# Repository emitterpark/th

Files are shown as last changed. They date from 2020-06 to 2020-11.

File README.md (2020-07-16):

**LoRaWAN Outdoor Temperature & Humidity Sensor**

**SENSOR**

**Temperature;**

Range -40 to +125 C

Resolution 0.01 C

Accuracy tolerance +-0.2 C

**Humidity;**

Range 0 to 100 %RH

Resolution 0.01 %RH

Accuracy tolerance +-2 %RH

High and Low Alarms with hysteresis

**RADIO**

LoRaWAN Class A

Licence Free ISM Bands (EU868, US915..), Default EU868, 8 Channel

Up to 100mW (20dbm) output power

High sensitivity -148dbm

3dbi External Antenna

Long Range, greater than 10km line of sight

**POWER**

3.6V 9000mah ER26500 C Size LiSClO2

15uA sleep current

Up to 5 years battery life depending on send interval

Low battery alarm

**CONFIGURATION**

Configuration via USB, Pc, Phone, Tablet

Send Interval, 5min to 24h

High and Low Alarm thresholds

Full LoRaWAN parameters access

Over The Air Activation (OTAA) with DevEUI, AppEUI, AppKEY

**PHYSICAL**

Outdoor IP65 waterproof enclosure

Mounting flanges

76X70X40mm

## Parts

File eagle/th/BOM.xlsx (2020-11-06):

IC1 | 1 | ATMEGA32U4-MU | QFN-44
IC2 | 1 | MCP1700T-3602E/TT | SOT23-3
MOD1 | 1 | RAK4200 LORA MODULE EU868MHZ | SM-20 | link (https://store.rakwireless.com/products/rak4200-lora-module?variant=31767678091309)
Q1,2 | 2 | SI2301BDS | SOT23-3
D1 | 1 | B5817W (MBR120) | SOD123
D2 | 1 | BZT52C3V9 | SOD123
LED1 | 1 | LED RED | 0805
XT1 | 1 | CRYSTAL PASSIVE 8MHZ 4PIN | 5032
F1 | 1 | PTC RESETTABLE FUSE 0.5A | 1206
SW1 | 1 | PUSH BUTTON 5.2X5.2MM 4P | SM
SW2 | 1 | REED SWITCH <=10MM NO | DIP
BAT1 | 1 | 211P-C PCB PIN C SIZE BATTERY HOLDER | DIP
CON1 | 1 | HEADER MALE 2.54MM 6P 2R | DIP
CON2 | 1 | HEADER MALE 2.54MM 8P 2R | DIP
CON3 | 1 | CONNECTOR RF SMA R/A FEMALE 20MM | DIP | link (https://www.aliexpress.com/item/33001356841.html?spm=a2g0o.detail.1000023.2.57702e34zxfXmB)
CON4 | 1 | USB3131 MICRO B USB VERTICAL FEMALE | DIP
CON5 | 1 | HEADER FEMALE 2.54MM 6P 1R | DIP
J1 | 1 | HEADER MALE 2.54MM 2P 1R | DIP
C1,6,10,12,13 | 5 | 10UF X5R/X7R | 0603
C2,5,7,11,14,15,17,18,19,20 | 10 | 100NF X5R/X7R | 0603
C3,4 | 2 | 22PF X5R/X7R | 0603
C8,9 | 2 | 10UF X5R/X7R | 0805
C16 | 1 | 1000UF 10MM | DIP
R1,2 | 2 | 22R %1 | 0603
R3,8,10,11,12,14,18 | 7 | 10K %1 | 0603
R4 | 1 | 220R %1 | 0603
R5,7,9 | 3 | 100R %1 | 0603
R6 | 0 | NC | 0603
R13 | 1 | 1M %1 | 0603
R15,16,17 | 3 | 1K %1 | 0603
R19 | 1 | NC | 0603
PCB | 1 | FR4 1.6MM 67.8X61.7 MM (2670X2430 MIL)
BATTERY | 1 | ER26500 3.6V 9000MAH C SIZE LISCLO2
ANTENNA | 1 | 868MHZ 5DBI SMA-MALE WHIP |  | link (https://www.aliexpress.com/item/32921464471.html?spm=2114.12010612.8148356.36.3e3f1f0b2ckfAt)
ENCLOSURE | 1 | H-393 IP65 76X70X40MM
SENSOR SHELL/COVER PLASTIC | 1 | TEMPERATURE & HUMIDITY
JUMPER | 4 | 2.54MM

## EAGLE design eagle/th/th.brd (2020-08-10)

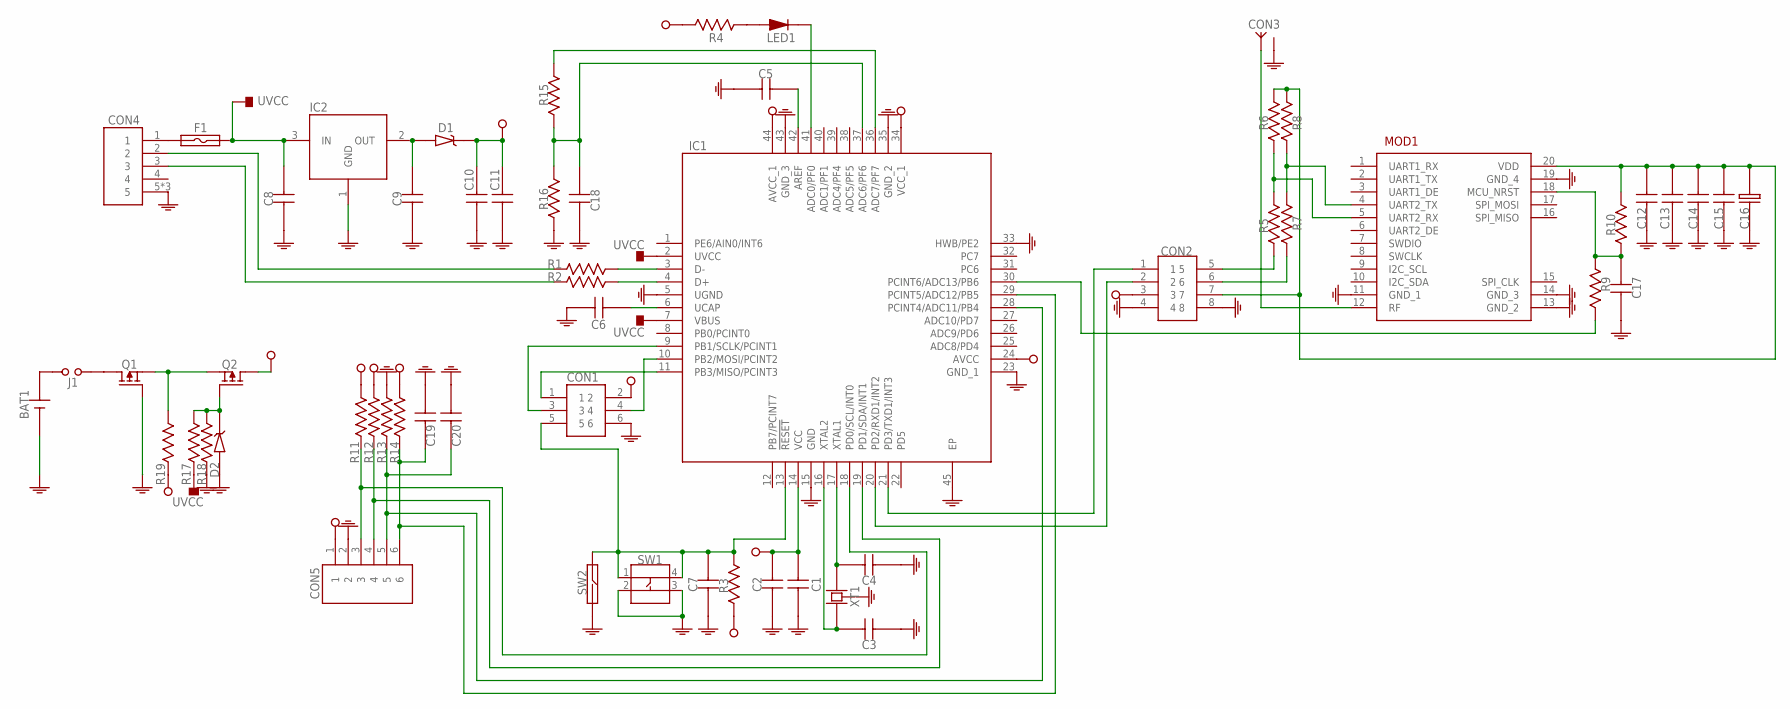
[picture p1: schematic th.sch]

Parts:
BAT1: 211P-C-HOLDER
C1, C2, C3, C4, C5, C6, C7, C10, C11, C12, C13, C14, C15, C17, C18, C19, C20: CAPACITOR-0603; 0603
C8, C9: CAPACITOR-0805; 0805
C16: CAPACITOR-10-5
CON1: ISP
CON2: HEADER-8P-2R-DIP-2_54MM
CON3: SMA-RF
CON4: USB-MICRO-DIP-VER
CON5: HEADER-6P-DIP-2_54MM
D1: DIODE-SCHOTTKY; SOD123-DIODE
D2: ZENER-SOD123; SOD123-DIODE
F1: FUSE-1206; 1206
IC1: ATMEGA32U4-MU; QFN-44
IC2: VREG-SOT23-3; SOT23-3
J1: JUMPER; HEADER-2P-DIP-2_54MM
LED1: LED-0805; 0805-LED
MOD1: RAK4200
Q1, Q2: P-MOSFET; SOT23-3
R1, R2, R3, R4, R5, R6, R7, R8, R9, R10, R11, R12, R13, R14, R15, R16, R17, R18, R19: RESISTOR-0603; 0603
SW1: BUTTON-4P-SMD-5X5
SW2: REED-DIP
XT1: CRYSTAL-5032-4P

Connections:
GND: BAT1.2 (-), C1.1, C2.1, C3.1, C4.1, C5.1, C6.1, C7.1, C8.1, C9.1, C10.1, C11.1, C12.1, C13.1, C14.1, C15.1, C16.P$1 (1), C17.1, C18.1, C19.1, C20.1, CON1.6, CON2.4, CON2.8, CON3.2 (GND), CON3.3 (GND), CON3.4 (GND), CON3.5 (GND), CON4.5, CON4.6 (5), CON4.7 (5), CON5.2, D2.2 (A), IC1.5 (UGND), IC1.15 (GND), IC1.23 (GND_1), IC1.33 (HWB/PE2), IC1.35 (GND_2), IC1.43 (GND_3), IC1.45 (EP), IC2.1 (GND), MOD1.11 (GND_1), MOD1.13 (GND_2), MOD1.14 (GND_3), MOD1.19 (GND_4), Q1.1 (G), R13.1, R16.1, R18.1, SW1.2, SW1.3, SW2.P$2 (2), XT1.2 (GND), XT1.4 (GND)
unnamed: C7.2, CON1.5, IC1.13 (!RESET), R3.2, SW1.1, SW1.4, SW2.P$1 (1)
unnamed: C17.2, MOD1.18 (MCU_NRST), R9.1, R10.1
unnamed: CON1.1, IC1.11 (PB3/MISO/PCINT3)
unnamed: CON3.1 (ANT), MOD1.12 (RF)
unnamed: J1.1, Q1.3 (D)
unnamed: CON2.5, R5.1
unnamed: CON2.6, R7.1
unnamed: BAT1.1 (+), J1.2 (3)
unnamed: CON1.4, IC1.10 (PB2/MOSI/PCINT2)
unnamed: C3.2, IC1.16 (XTAL2), XT1.1
unnamed: CON2.2, IC1.20 (PD2/RXD1/INT2)
unnamed: C4.2, IC1.17 (XTAL1), XT1.3 (2)
unnamed: IC1.41 (ADC0/PF0), LED1.1 (K)
unnamed: C20.2, CON5.5, IC1.28 (PCINT4/ADC11/PB4), R13.2
unnamed: C9.2, D1.2 (A), IC2.2 (OUT)
unnamed: IC1.30 (PCINT6/ADC13/PB6), R9.2
unnamed: CON4.2, R1.1
unnamed: IC1.3 (D-), R1.2
unnamed: IC1.4 (D+), R2.2
unnamed: C18.2, IC1.37 (ADC6/PF6), R15.2, R16.2
unnamed: D2.1 (K), Q2.1 (G), R17.2, R18.2
unnamed: C12.2, C13.2, C14.2, C15.2, C16.P$2 (2), CON2.7, MOD1.20 (VDD), R6.2, R8.2, R10.2
unnamed: CON2.1, IC1.21 (PD3/TXD1/INT3)
unnamed: CON4.3, R2.1
unnamed: C19.2, CON5.6, IC1.29 (PCINT5/ADC12/PB5), R14.2
unnamed: Q1.2 (S), Q2.2 (S), R19.2
unnamed: MOD1.4 (UART2_TX), R7.2, R8.1
unnamed: C5.2, IC1.42 (AREF)
unnamed: MOD1.5 (UART2_RX), R5.2, R6.1
unnamed: CON4.1, F1.1
unnamed: C6.2, IC1.6 (UCAP)
unnamed: LED1.2 (A), R4.1
unnamed: IC1.36 (ADC7/PF7), R15.1
unnamed: CON1.3, IC1.9 (PB1/SCLK/PCINT1)
unnamed: CON5.3, IC1.18 (PD0/SCL/INT0), R11.2
unnamed: CON5.4, IC1.19 (PD1/SDA/INT1), R12.2
UVCC: C8.2, F1.2, IC1.2 (UVCC), IC1.7 (VBUS), IC2.3 (IN), R17.1
VCC: C1.2, C2.2, C10.2, C11.2, CON1.2, CON2.3, CON5.1, D1.1 (K), IC1.14 (VCC), IC1.24 (AVCC), IC1.34 (VCC_1), IC1.44 (AVCC_1), Q2.3 (D), R3.1, R4.2, R11.1, R12.1, R14.1, R19.1

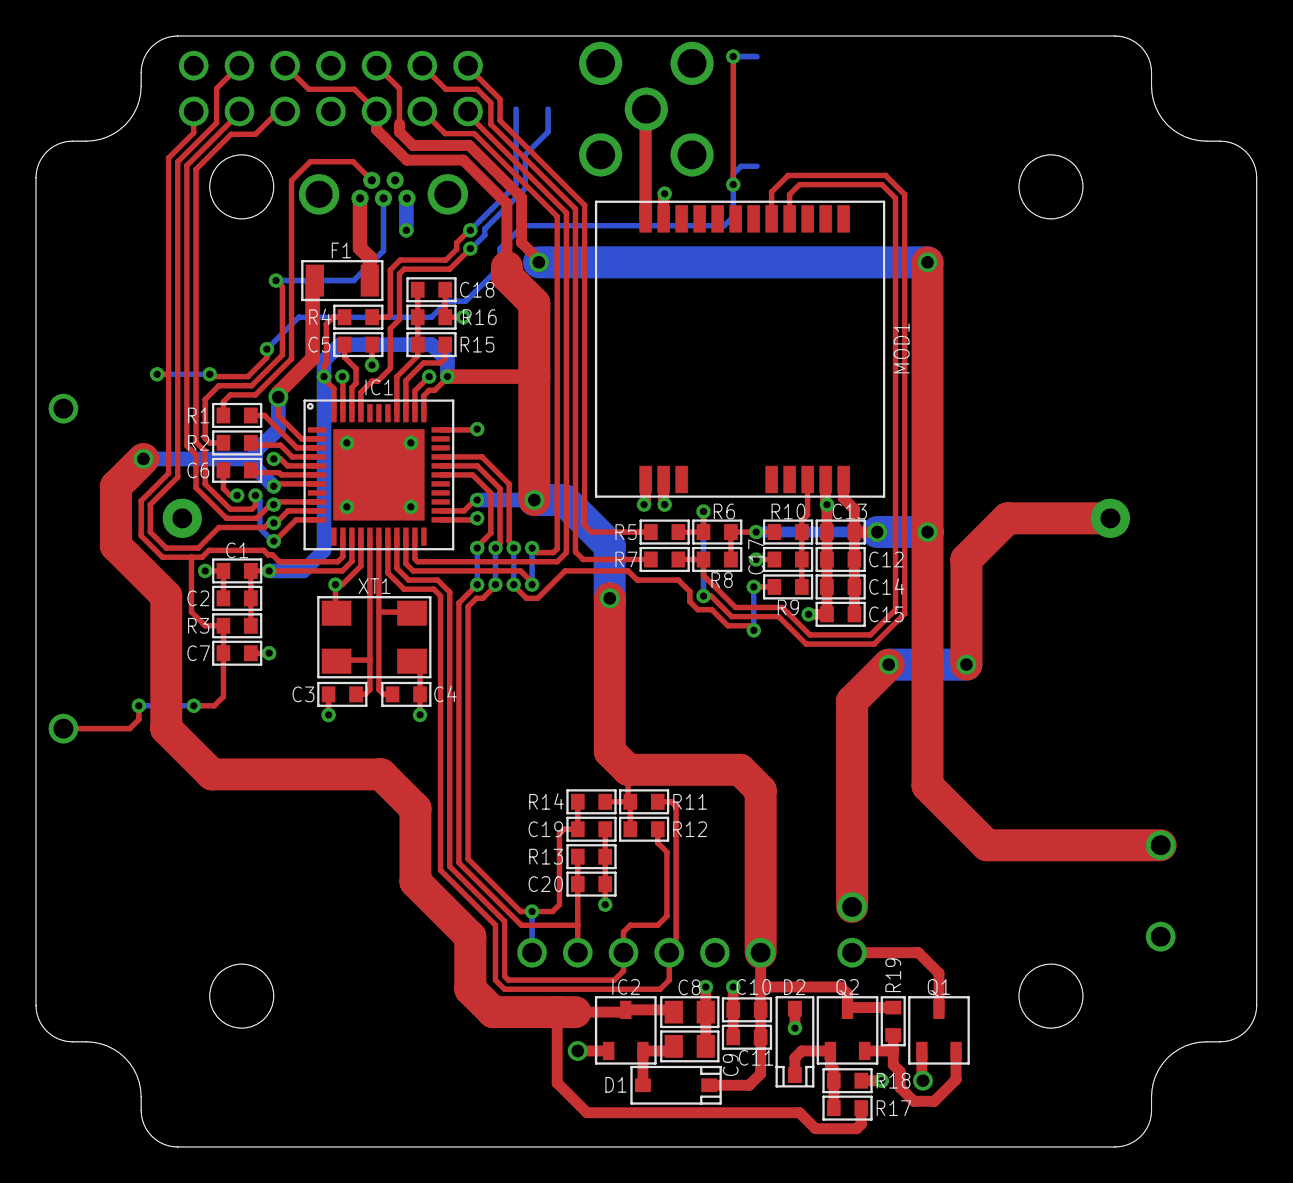
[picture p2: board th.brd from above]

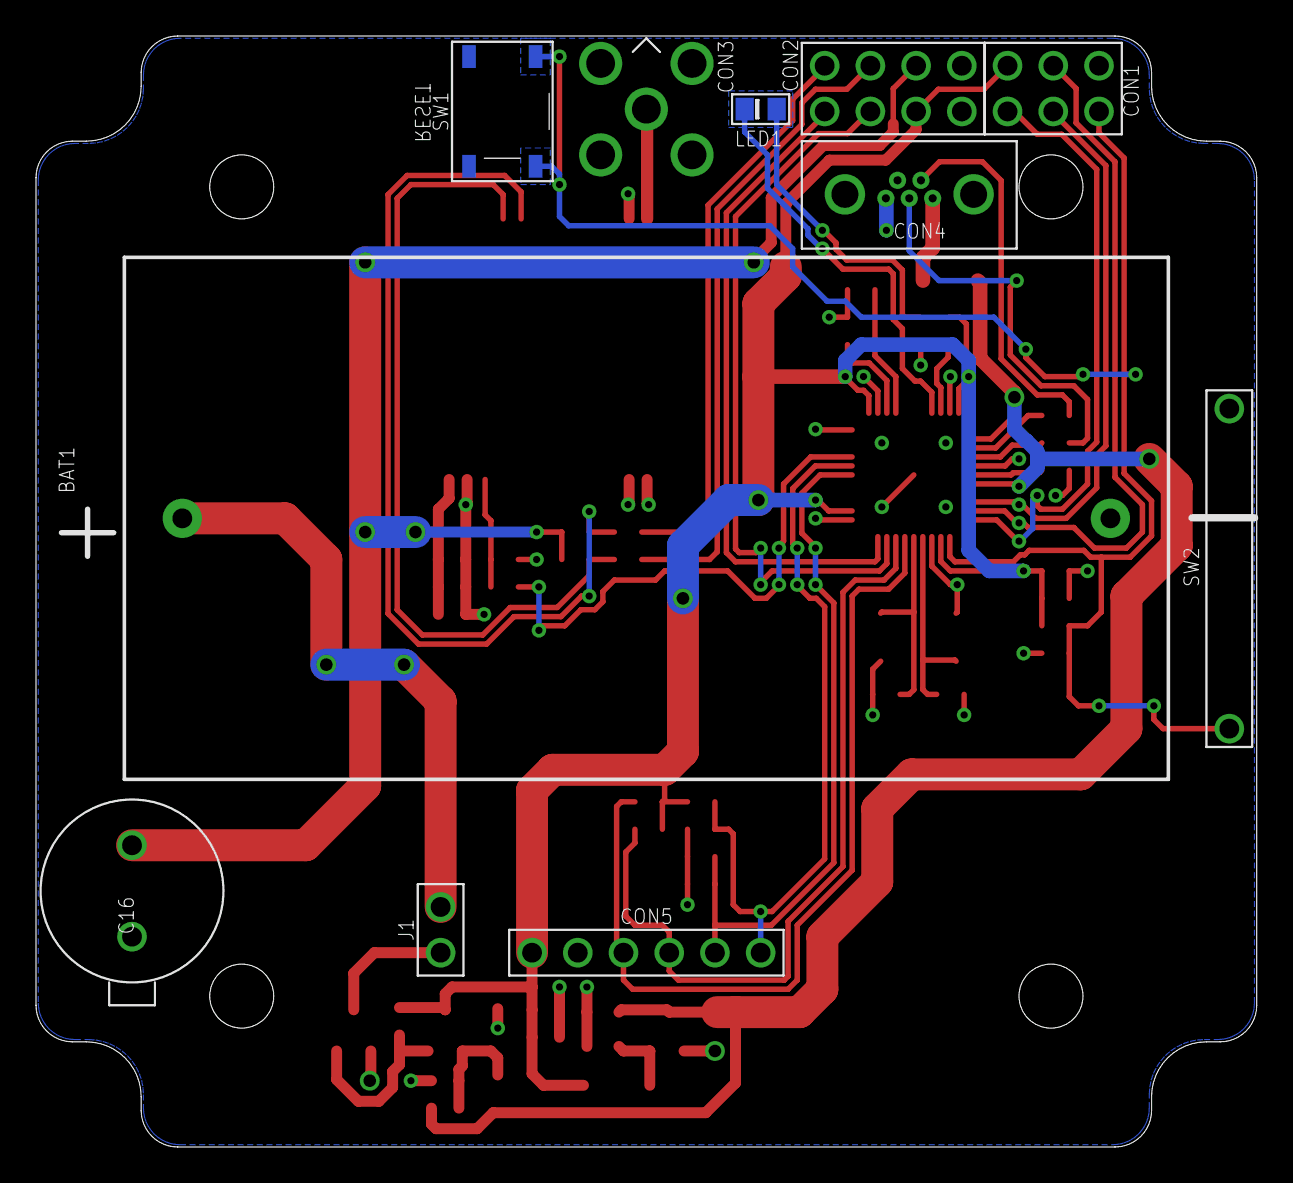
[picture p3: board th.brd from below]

Board: 2 copper layers, 67.8 x 61.7 mm, 58 parts (11 on the bottom side), 39 nets.

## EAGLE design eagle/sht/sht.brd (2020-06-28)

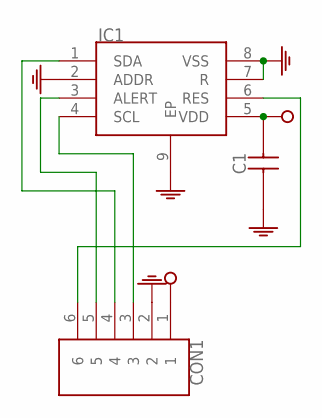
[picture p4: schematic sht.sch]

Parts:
C1: CAPACITOR-0603; 0603
CON1: HEADER-6P-DIP-2_54MM
IC1: SHT3X-DIS

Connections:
GND: C1.1, CON1.2, IC1.2 (ADDR), IC1.7 (R), IC1.8 (VSS), IC1.9 (EP)
unnamed: CON1.6, IC1.6 (RES)
unnamed: CON1.4, IC1.1 (SDA)
unnamed: CON1.3, IC1.4 (SCL)
unnamed: CON1.5, IC1.3 (ALERT)
VCC: C1.2, CON1.1, IC1.5 (VDD)

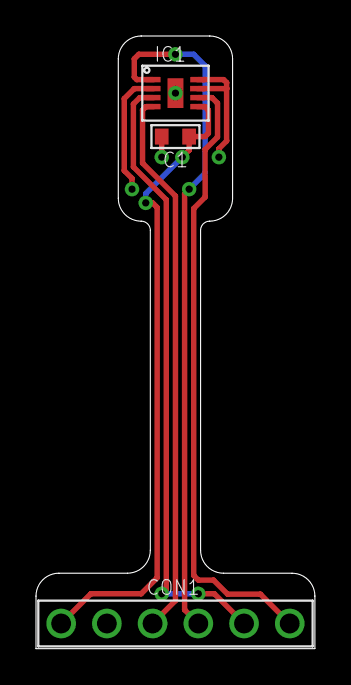
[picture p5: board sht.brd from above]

Board: 2 copper layers, 15.5 x 34.0 mm, 3 parts (0 on the bottom side), 6 nets.

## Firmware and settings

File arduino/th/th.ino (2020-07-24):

// Bootloader: Board SparkFun Pro Micro 3.3V 8MHZ
// sparkfun boards.txt 
// promicro.menu.cpu.8MHzatmega32U4.bootloader.extended_fuses=0xFF
// promicro.build.extra_flags={build.usb_flags} "-DUSB_VERSION=0x210"
// or C:Users/../AppData/Local/Arduino../packages/arduino/hardware/avr/../cores/arduino/USBCore.h 
// line 130: #define USB_VERSION 0x210

#include <avr/wdt.h>
#include "LowPower.h"             // https://github.com/rocketscream/Low-Power
#include <EEPROM.h>
#include <CayenneLPP.h>           // https://github.com/ElectronicCats/CayenneLPP
#include <Wire.h>
#include "ClosedCube_SHT31D.h"    // https://github.com/closedcube/ClosedCube_SHT31D_Arduino
#include <WebUSB.h>               // https://github.com/webusb/arduino

const uint8_t TXD1_PIN            = 1;                // PD3/TXD1/INT3
const uint8_t AN_ALR_PIN          = 8;                // PB4/ADC11/PCINT4
const uint8_t AN_RES_PIN          = 9;                // PB5/ADC12/PCINT5
const uint8_t LORA_RES_PIN        = 10;               // PB6/ADC13/PCINT6
const uint8_t BAT_EN_PIN          = A0;               // PF7/ADC7
const uint8_t BAT_PIN             = A1;               // PF6/ADC6
const uint8_t LED_PIN             = A5;               // PF0/ADC0

const uint8_t lru08_dr            = 0;  
const uint8_t lru08_port          = 1;  
const uint8_t lru08_report        = 2;

const uint8_t anf32_low_set       = 0;
const uint8_t anf32_low_clear     = 1;  
const uint8_t anf32_high_set      = 2;
const uint8_t anf32_high_clear    = 3; 

const uint8_t numAn               = 2;
float         an[numAn];

struct Conf {
  uint8_t   lru08[3];  
  float     anf32[4 * numAn];      
};
Conf conf;

bool isLoraJoin, isUsb, isCpuSleepEn;
volatile bool isAlarm = false;
unsigned long fetchTmrLog, fetchTmr = 10000L, sleepTmrLog, sleepTmr = 60000L;
String strUsbSerial, strLoraSerial;
float batVolt;
const float batCalb = 1.025;
const uint8_t batEnDly = 1, batSampDly = 1, batSampNum = 3;

CayenneLPP lpp(51);
ClosedCube_SHT31D analog;
//WebUSB WebUSBSerial(1 /* https:// */, "emitterpark.github.io/th");
WebUSB WebUSBSerial(1 /* https:// */, "127.0.0.1:5500");
#define usbSerial WebUSBSerial
#define loraSerial Serial1

void setup() {  
  analogReference(INTERNAL); 
  setPin();
  loadConf(); 
  setUsbSerial();   
  setAnalog();
  setLoraSerial();
  printAll();
  fetchTmrLog = millis();
  sleepTmrLog = millis();  
}
void loop() {
  readLoraSerial();
  if (isUsb) {
    readUsbSerial();
    if (millis() - fetchTmrLog >= fetchTmr) {
      fetchTmrLog = millis();
      readAnalog();
      printChFetch();  
    }    
  } else if (isCpuSleepEn) {
    sleepCpu();  
  } else if (millis() - sleepTmrLog >= sleepTmr) {
    sleepLora();  
  }
}
void report() {      
  printMsg(F("report"));
  readBattery();
  readAnalog(); 
  lpp.reset();  
  lpp.addTemperature(1, an[0]);
  lpp.addRelativeHumidity(2, an[1]);
  lpp.addAnalogInput(3, batVolt);
  delay(10); 
  loraSerial.print("at+send=lora:" + String(conf.lru08[lru08_port]) + ':'); 
  loraSerial.println(lppGetBuffer());       
}
void sleepCpu() {
  digitalWrite(LED_PIN, HIGH);  
  for (uint16_t slpCnt = 0; slpCnt < conf.lru08[lru08_report] * (60 / 8 - 1) ; slpCnt++) {      
    setAlr();
    endLoraSerial();    
    LowPower.powerDown(SLEEP_8S, ADC_OFF, BOD_OFF);    
    if (isAlarm) {
      isAlarm = false;      
      if (isLoraJoin) {
        beginLoraSerial();                
        wakeLora(); 
        return;   
      }             
    }                  
  }  
  if (!isLoraJoin) {          
    resetCpu();    
  }
  beginLoraSerial();          
  wakeLora();  
}
void readLoraSerial() { 
  while (loraSerial.available()) {    
    const char chr = (char)loraSerial.read();    
    strLoraSerial += chr;
    if (chr == '\n') {
      strLoraSerial.trim();
      if (strLoraSerial.endsWith(F("Join Success"))) {               
        delay(10);         
        loraSerial.print(F("at+set_config=lora:dr:")); 
        loraSerial.println(conf.lru08[lru08_dr]); 
      } else if (strLoraSerial.endsWith(F("JOIN_FAIL 99"))) {
        isLoraJoin = false;
        printMsg(F("xjoinlrwCould not Join to Network"));                 
        sleepLora(); 
      } else if (strLoraSerial.indexOf(F("Join retry")) >= 0) {
        isLoraJoin = false;
        printMsg(F("xjoinlrwJoining to Network .."));         
      } else if (strLoraSerial.indexOf(F("NO_NETWORK")) >= 0) {
        isLoraJoin = false;
        printMsg(F("xjoinlrwCould not Join to Network"));        
        sleepLora();        
      } else if (strLoraSerial.indexOf(F("configure DR")) >= 0) {
        isLoraJoin = true;
        printMsg(F("xjoinlrwJoin Success"));        
        sleepLora();            
      } else if (strLoraSerial.endsWith(F("send success"))) {
        sleepLora();            
      } else if (strLoraSerial.endsWith(F("Go to Sleep"))) {                
        isCpuSleepEn = true;                         
      } else if (strLoraSerial.endsWith(F("Wake up."))) {
        report();   
      } else if (strLoraSerial.startsWith(F("ERROR"))) {        
        sleepLora();     
      }
      if (isUsb) {
        usbSerial.println(strLoraSerial); 
        usbSerial.flush();
      }           
      strLoraSerial = "";
    }
  }
}
void readUsbSerial() {
  while (usbSerial && usbSerial.available()) {    
    const char chr = (char)usbSerial.read();
    strUsbSerial += chr;
    if (chr == '\n') {
      strUsbSerial.trim();
      const uint8_t num = strUsbSerial.substring(6, 8).toInt();
      const uint16_t valInt = strUsbSerial.substring(8).toInt();
      const float valFloat = strUsbSerial.substring(8).toFloat();       
      if (strUsbSerial.startsWith(F("at"))) {
        loraSerial.println(strUsbSerial);      
      } else if (strUsbSerial.startsWith(F("xlru08"))) {
        conf.lru08[num] = (uint8_t)valInt;
      } else if (strUsbSerial.startsWith(F("xanf32"))) {
        conf.anf32[num] = valFloat;
      } else if (strUsbSerial.startsWith(F("xsave"))) {
        EEPROM.put(0, conf);
        resetCpu();     
      } else if (strUsbSerial.startsWith(F("xreport"))) {
        wakeLora();           
      }
      strUsbSerial = "";
    }
  }   
}
void readAnalog() {
  SHT31D result = analog.periodicFetchData();
  an[0] = result.t;
  an[1] = result.rh;  
  isAlarm = false;
}
void readBattery() {  
  pinMode(BAT_EN_PIN, OUTPUT);
  digitalWrite(BAT_EN_PIN, HIGH);
  delay(batEnDly);
  uint16_t samples[batSampNum];
  for (uint8_t ii = 0; ii < batSampNum; ii++) {
    samples[ii] = analogRead(BAT_PIN);
    delay(batSampDly);
  } 
  pinMode(BAT_EN_PIN, INPUT);
  pwrDownAdc();
  pwrDownRef(); 
  batVolt = 0;
  for (uint8_t jj = 0; jj < batSampNum; jj++) {
    batVolt += samples[jj];
  }
  batVolt /= batSampNum;   
  batVolt = ( batVolt / 1023 ) * 2.56 * 2 * batCalb;  
}
void loadConf() {
  EEPROM.get(0, conf);  
}
void setPin() {  
  pinMode(AN_ALR_PIN, INPUT);
  pinMode(AN_RES_PIN, OUTPUT);
  pinMode(LORA_RES_PIN, OUTPUT);
  pinMode(BAT_EN_PIN, INPUT);  
  pinMode(LED_PIN, OUTPUT);
  digitalWrite(AN_RES_PIN, LOW);
  digitalWrite(LORA_RES_PIN, LOW);
  digitalWrite(LED_PIN, LOW);  
}
void setAnalog() {
  delay(100);
  digitalWrite(AN_RES_PIN, HIGH);
  delay(100);
  Wire.begin();
  analog.begin(0x44);  
  analog.periodicStart(SHT3XD_REPEATABILITY_LOW, SHT3XD_FREQUENCY_HZ5);
  const uint8_t _t_low_set = anf32_low_set + 0 * (sizeof(conf.anf32) / sizeof(conf.anf32[0])) / numAn;
  const uint8_t _t_low_clear = anf32_low_clear + 0 * (sizeof(conf.anf32) / sizeof(conf.anf32[0])) / numAn;
  const uint8_t _t_high_set = anf32_high_set + 0 * (sizeof(conf.anf32) / sizeof(conf.anf32[0])) / numAn;
  const uint8_t _t_high_clear = anf32_high_clear + 0 * (sizeof(conf.anf32) / sizeof(conf.anf32[0])) / numAn;
  const uint8_t _r_low_set = anf32_low_set + 1 * (sizeof(conf.anf32) / sizeof(conf.anf32[0])) / numAn;
  const uint8_t _r_low_clear = anf32_low_clear + 1 * (sizeof(conf.anf32) / sizeof(conf.anf32[0])) / numAn;
  const uint8_t _r_high_set = anf32_high_set + 1 * (sizeof(conf.anf32) / sizeof(conf.anf32[0])) / numAn;
  const uint8_t _r_high_clear = anf32_high_clear + 1 * (sizeof(conf.anf32) / sizeof(conf.anf32[0])) / numAn;  
  analog.writeAlertHigh(conf.anf32[_t_high_set], conf.anf32[_t_high_clear], conf.anf32[_r_high_set], conf.anf32[_r_high_clear]);
  analog.writeAlertLow(conf.anf32[_t_low_clear], conf.anf32[_t_low_set], conf.anf32[_r_low_clear], conf.anf32[_r_low_set]);
  readAnalog();
  analog.clearAll(); 
  delay(10);      
}
void setAlr(){
  *digitalPinToPCMSK(AN_ALR_PIN) |= bit (digitalPinToPCMSKbit(AN_ALR_PIN));
  PCIFR  |= bit (digitalPinToPCICRbit(AN_ALR_PIN));
  PCICR  |= bit (digitalPinToPCICRbit(AN_ALR_PIN));
  isAlarm = false;
}
ISR (PCINT0_vect) {  
  isAlarm = true;  
}
void setLoraSerial() {  
  beginLoraSerial();  
  pinMode(LORA_RES_PIN, INPUT);  
  delay(1000);
  wakeLora();      
}
void beginLoraSerial() {
  loraSerial.begin(115200);
  //UCSR1B |= _BV(TXEN1);   //enable TX
  delay(10);  
}
void endLoraSerial() {
  loraSerial.end();
  //UCSR1B &= ~_BV(TXEN1);  //disable TX 
  digitalWrite(TXD1_PIN, LOW);
}
void wakeLora() {
  digitalWrite(LED_PIN, LOW);
  isCpuSleepEn = false;
  sleepTmrLog = millis();
  delay(10);
  loraSerial.println("at+version");
}
void sleepLora() {
  sleepTmrLog = millis();
  delay(10);
  loraSerial.print(F("at+set_config=device:sleep:1"));    
}
void setUsbSerial() {
  if (USBSTA >> VBUS & 1) {          
    while (!usbSerial) {      
    }
    usbSerial.begin(9600);  
    usbSerial.flush();
    isUsb = true;
  } else {
    pwrDownUsb();
    pwrDownAdc();
    pwrDownRef(); 
  }      
}
void printAll() {
  printChFetch();
  printMsg(F("xdeviceeLoraWAN Wireless TH"));   
  printMsg(F("xversionFirmware 1.0.1"));
  printChConf();
  printLoraConf();
  printLoraKeys();
  printMsg(F("xjoinlrwJoining to Network .."));
}
void printMsg(String msg) {
  if (!isUsb) {
    return;
  }
  usbSerial.println(msg);
  usbSerial.flush();
}
void printChFetch() {
  if (!isUsb) {
    return;
  }
  String str;
  for (uint8_t ch = 0; ch < numAn; ch++) {      
    usbSerial.print(F("xanval"));    
    str = '0' + String(ch);
    usbSerial.print(str.substring(str.length() - 2));    
    usbSerial.println(an[ch], 2);
    usbSerial.flush();       
  }
}
void printChConf() {
  if (!isUsb) {
    return;
  }
  String str;
  for (uint8_t i = 0; i < (sizeof(conf.anf32) / sizeof(conf.anf32[0])); i++) {
    usbSerial.print(F("xanf32"));    
    str = '0' + String(i);
    usbSerial.print(str.substring(str.length() - 2));    
    usbSerial.println(conf.anf32[i], 2); 
    usbSerial.flush();   
  }  
}
void printLoraConf() {
  if (!isUsb) {
    return;
  }
  String str;
  for (uint8_t i = 0; i < sizeof(conf.lru08); i++) {    
    usbSerial.print(F("xlru08"));    
    str = '0' + String(i);
    usbSerial.print(str.substring(str.length() - 2));    
    usbSerial.println(conf.lru08[i]);
    usbSerial.flush();    
  } 
}
void printLoraKeys() {
  if (!isUsb) {
    return;
  }
  delay(10);         
  loraSerial.println(F("at+get_config=lora:status")); 
}
void pwrDownUsb() {
  USBDevice.detach();
  USBCON |= _BV(FRZCLK);  
  PLLCSR &= ~_BV(PLLE);   
  USBCON &= ~_BV(USBE);   
  USBCON &= ~_BV(OTGPADE);
  USBCON &= ~_BV(VBUSTE);
  UHWCON &= ~_BV(UVREGE);
}
void pwrDownAdc() {
  ADCSRA &= ~_BV(ADEN);
}
void pwrDownRef() {
  ACSR &= ~_BV(ACIE);
  ACSR |= _BV(ACD);
}
void resetCpu() {
  wdt_enable(WDTO_15MS);
  while(true);  
}
String lppGetBuffer() {
  String str;
  for(uint8_t i = 0; i < lpp.getSize(); i++){    
    if (lpp.getBuffer()[i] < 16) {
      str += '0';       
    }
    str += String(lpp.getBuffer()[i], HEX);
    str.toUpperCase();        
  }
  return str;
}

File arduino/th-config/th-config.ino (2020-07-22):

#include <EEPROM.h>

const uint8_t numAn                     = 2;

struct Conf {
  const uint8_t   lru08[3]              = {2,90,5};  
  const float     anf32[4 * numAn]      = {20,22,40,38,20,25,80,75};  
};

Conf conf;

void setup() {
  for (int i = 0 ; i < EEPROM.length() ; i++) {
    EEPROM.write(i, 0);
  }
  EEPROM.put(0, conf);
}

void loop() {
}
